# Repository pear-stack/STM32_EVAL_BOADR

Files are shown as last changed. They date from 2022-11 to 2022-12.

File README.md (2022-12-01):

# STM32_EVAL_BOARD
Simple STM32 Hardware Design
<p align="center">

</p>
<p align="center">

</p>

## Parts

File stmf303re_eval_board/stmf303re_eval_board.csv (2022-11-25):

Source: | /home/smuff/Documents/Projects/stmf303re_eval_board/stmf303re_eval_board/stmf303re_eval_board.kicad_sch
Date: | pią, 25 lis 2022, 11:23:28
Tool: | Eeschema (6.0.9)
Generator: | /usr/share/kicad/plugins/bom_csv_grouped_by_value.py
Component Count: | 31
Individual Components:
Item | Qty | Reference(s) | Value | LibPart | Footprint | Datasheet
 |  | C1 | 10u | Device:C | Capacitor_SMD:C_0603_1608Metric | ~
 |  | C2 | 100n | Device:C | Capacitor_SMD:C_0402_1005Metric | ~
 |  | C3 | 100n | Device:C | Capacitor_SMD:C_0402_1005Metric | ~
 |  | C4 | 100n | Device:C | Capacitor_SMD:C_0402_1005Metric | ~
 |  | C5 | 1u | Device:C | Capacitor_SMD:C_0603_1608Metric | ~
 |  | C6 | 100n | Device:C | Capacitor_SMD:C_0402_1005Metric | ~
 |  | C7 | 100n | Device:C | Capacitor_SMD:C_0402_1005Metric | ~
 |  | C8 | 100n | Device:C | Capacitor_SMD:C_0402_1005Metric | ~
 |  | C9 | 100n | Device:C | Capacitor_SMD:C_0402_1005Metric | ~
 |  | C10 | 30p | Device:C | Capacitor_SMD:C_0402_1005Metric | ~
 |  | C11 | 30p | Device:C | Capacitor_SMD:C_0402_1005Metric | ~
 |  | C12 | 1u | Device:C | Capacitor_SMD:C_0603_1608Metric | ~
 |  | C13 | 1u | Device:C | Capacitor_SMD:C_0603_1608Metric | ~
 |  | D1 | RED | Device:LED | LED_SMD:LED_0805_2012Metric | ~
 |  | D2 | GREEN | Device:LED | LED_SMD:LED_0805_2012Metric | ~
 |  | FB1 | 100R | Device:FerriteBead | Inductor_SMD:L_0805_2012Metric | ~
 |  | J1 | Conn_01x04_Male | Connector:Conn_01x04_Male | Connector_PinHeader_2.54mm:PinHeader_1x04_P2.54mm_Vertical | ~
 |  | J2 | USB_B_Micro | Connector:USB_B_Micro | Connector_USB:USB_Micro-B_Molex_47346-0001 | ~
 |  | J3 | Conn_01x16 | Connector_Generic:Conn_01x16 | Connector_PinSocket_2.54mm:PinSocket_1x16_P2.54mm_Vertical | ~
 |  | J4 | Conn_01x16 | Connector_Generic:Conn_01x16 | Connector_PinSocket_2.54mm:PinSocket_1x16_P2.54mm_Vertical | ~
 |  | JP1 | SolderJumper_2_Open | Jumper:SolderJumper_2_Open | Jumper:SolderJumper-2_P1.3mm_Open_RoundedPad1.0x1.5mm | ~
 |  | L1 | 27n | Device:L | Inductor_SMD:L_0402_1005Metric | ~
 |  | R1 | 10k | Device:R | Resistor_SMD:R_0603_1608Metric | ~
 |  | R2 | 10k | Device:R | Resistor_SMD:R_0603_1608Metric | ~
 |  | R3 | 1k5 | Device:R | Resistor_SMD:R_0603_1608Metric | ~
 |  | R4 | 1k5 | Device:R | Resistor_SMD:R_0603_1608Metric | ~
 |  | R5 | 1k5 | Device:R | Resistor_SMD:R_0603_1608Metric | ~
 |  | SW1 | SW_DPST_x2 | Switch:SW_DPST_x2 | Button_Switch_SMD:SW_SPST_CK_RS282G05A3 | ~
 |  | U1 | STM32F303RETx | MCU_ST_STM32F3:STM32F303RETx | Package_QFP:LQFP-64_10x10mm_P0.5mm | http://www.st.com/st-web-ui/static/active/en/resource/technical/document/datasheet/DM00118585.pdf
 |  | U2 | XC6206PxxxMR | Regulator_Linear:XC6206PxxxMR | Package_TO_SOT_SMD:SOT-23 | https://www.torexsemi.com/file/xc6206/XC6206.pdf
 |  | Y1 | 8MHz | Device:Crystal | Crystal:Crystal_SMD_0603-2Pin_6.0x3.5mm | ~
Collated Components:
Item | Qty | Reference(s) | Value | LibPart | Footprint | Datasheet
1 | 1 | C1 | 10u | Device:C | Capacitor_SMD:C_0603_1608Metric | ~
2 | 7 | C2, C3, C4, C6, C7, C8, C9 | 100n | Device:C | Capacitor_SMD:C_0402_1005Metric | ~
3 | 3 | C5, C12, C13 | 1u | Device:C | Capacitor_SMD:C_0603_1608Metric | ~
4 | 2 | C10, C11 | 30p | Device:C | Capacitor_SMD:C_0402_1005Metric | ~
5 | 1 | D1 | RED | Device:LED | LED_SMD:LED_0805_2012Metric | ~
6 | 1 | D2 | GREEN | Device:LED | LED_SMD:LED_0805_2012Metric | ~
7 | 1 | FB1 | 100R | Device:FerriteBead | Inductor_SMD:L_0805_2012Metric | ~
8 | 1 | J1 | Conn_01x04_Male | Connector:Conn_01x04_Male | Connector_PinHeader_2.54mm:PinHeader_1x04_P2.54mm_Vertical | ~
9 | 1 | J2 | USB_B_Micro | Connector:USB_B_Micro | Connector_USB:USB_Micro-B_Molex_47346-0001 | ~
10 | 2 | J3, J4 | Conn_01x16 | Connector_Generic:Conn_01x16 | Connector_PinSocket_2.54mm:PinSocket_1x16_P2.54mm_Vertical | ~
11 | 1 | JP1 | SolderJumper_2_Open | Jumper:SolderJumper_2_Open | Jumper:SolderJumper-2_P1.3mm_Open_RoundedPad1.0x1.5mm | ~
12 | 1 | L1 | 27n | Device:L | Inductor_SMD:L_0402_1005Metric | ~
13 | 2 | R1, R2 | 10k | Device:R | Resistor_SMD:R_0603_1608Metric | ~
14 | 3 | R3, R4, R5 | 1k5 | Device:R | Resistor_SMD:R_0603_1608Metric | ~
15 | 1 | SW1 | SW_DPST_x2 | Switch:SW_DPST_x2 | Button_Switch_SMD:SW_SPST_CK_RS282G05A3 | ~
16 | 1 | U1 | STM32F303RETx | MCU_ST_STM32F3:STM32F303RETx | Package_QFP:LQFP-64_10x10mm_P0.5mm | http://www.st.com/st-web-ui/static/active/en/resource/technical/document/datasheet/DM00118585.pdf
17 | 1 | U2 | XC6206PxxxMR | Regulator_Linear:XC6206PxxxMR | Package_TO_SOT_SMD:SOT-23 | https://www.torexsemi.com/file/xc6206/XC6206.pdf
18 | 1 | Y1 | 8MHz | Device:Crystal | Crystal:Crystal_SMD_0603-2Pin_6.0x3.5mm | ~

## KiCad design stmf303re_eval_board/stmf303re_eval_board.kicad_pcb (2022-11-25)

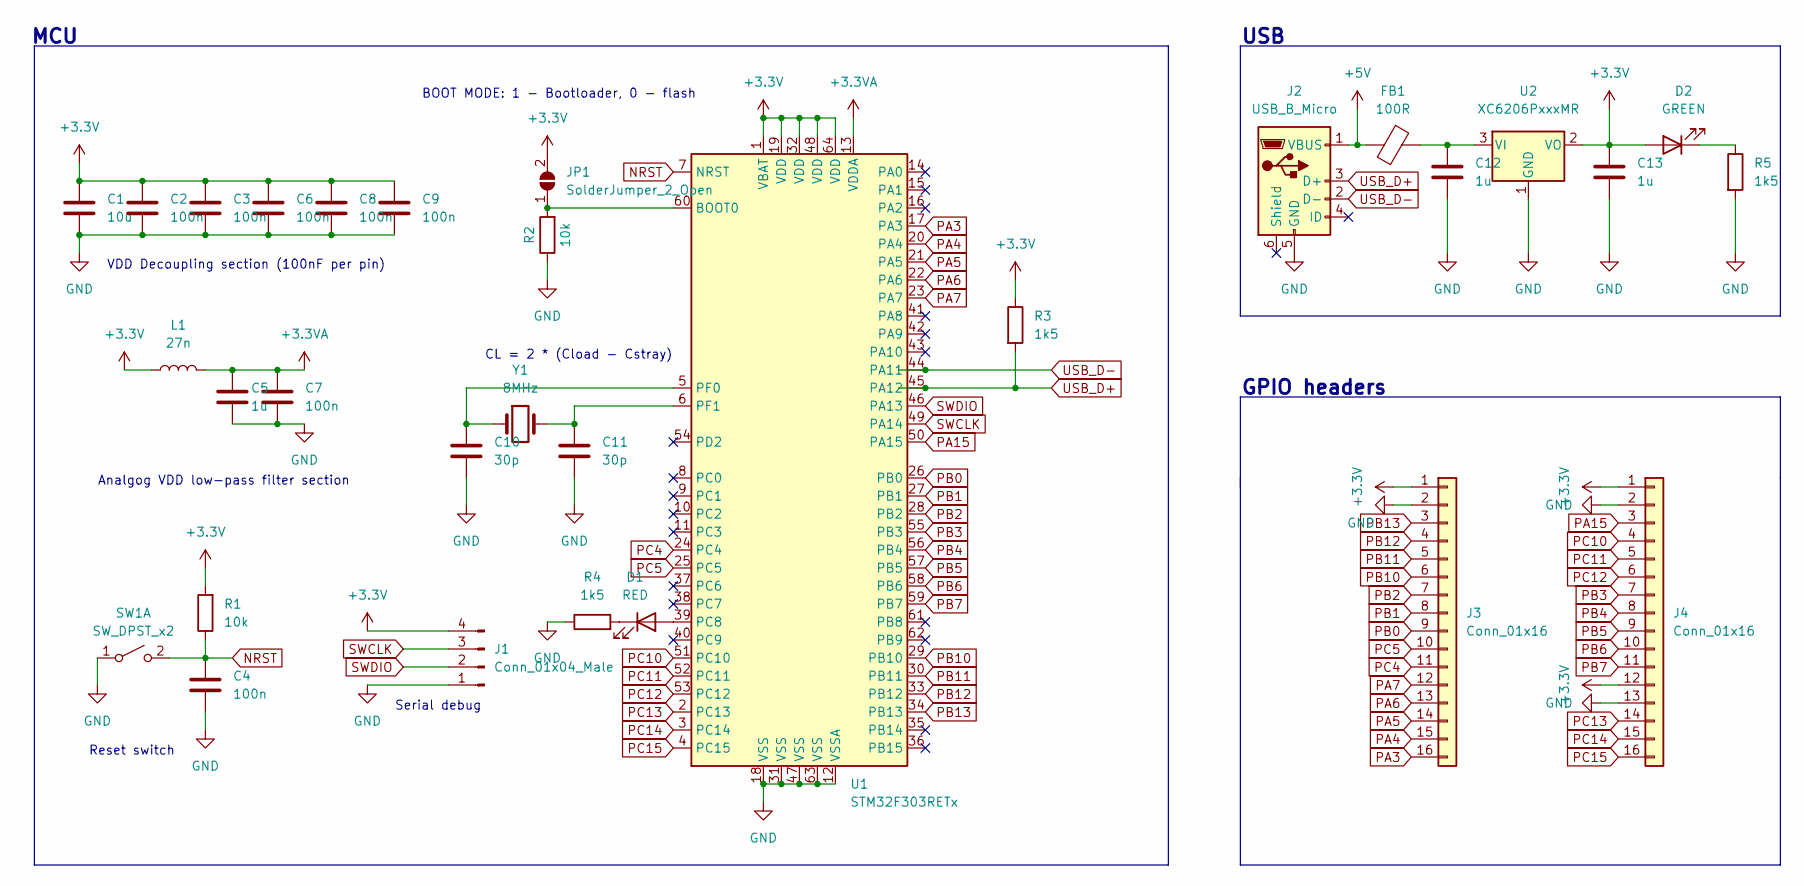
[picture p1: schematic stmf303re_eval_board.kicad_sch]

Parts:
C1: 10u; C_0603_1608Metric
C2, C3, C4, C6, C7, C8, C9: 100n; C_0402_1005Metric
C5, C12, C13: 1u; C_0603_1608Metric
C10, C11: 30p; C_0402_1005Metric
D1: RED; LED_0805_2012Metric
D2: GREEN; LED_0805_2012Metric
FB1: 100R; L_0805_2012Metric
J1: Conn_01x04_Male; PinHeader_1x04_P2.54mm_Vertical
J2: USB_B_Micro; USB_Micro-B_Molex_47346-0001
J3, J4: Conn_01x16; PinSocket_1x16_P2.54mm_Vertical
JP1: SolderJumper_2_Open; SolderJumper-2_P1.3mm_Open_RoundedPad1.0x1.5mm
L1: 27n; L_0402_1005Metric
R1, R2: 10k; R_0603_1608Metric
R3, R4, R5: 1k5; R_0603_1608Metric
SW1: SW_DPST_x2; SW_SPST_CK_RS282G05A3
U1: STM32F303RETx; LQFP-64_10x10mm_P0.5mm
U2: XC6206PxxxMR; SOT-23
Y1: 8MHz; Crystal_SMD_0603-2Pin_6.0x3.5mm

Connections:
+3.3V: C1.1, C2.1, C3.1, C6.1, C8.1, C9.1, C13.1, D2.2 (A), J1.4, J3.1, J4.1, J4.12, JP1.2 (B), L1.1, R1.2, R3.1, U1.1 (VBAT), U1.19 (VDD), U1.32 (VDD), U1.48 (VDD), U1.64 (VDD), U2.2 (VO)
+3.3VA: C5.1, C7.1, L1.2, U1.13 (VDDA)
+5V: FB1.1, J2.1 (VBUS)
GND: C1.2, C2.2, C3.2, C4.2, C5.2, C6.2, C7.2, C8.2, C9.2, C10.2, C11.2, C12.2, C13.2, J1.1, J2.5 (GND), J3.2, J4.2, J4.13, R2.1, R4.1, R5.2, SW1.1 (A), U1.12 (VSSA), U1.18 (VSS), U1.31 (VSS), U1.47 (VSS), U1.63 (VSS), U2.1 (GND)
NRST: C4.1, R1.1, SW1.2 (B), U1.7 (NRST)
unnamed: C10.1, U1.5 (PF0), Y1.1
unnamed: C11.1, U1.6 (PF1), Y1.2
unnamed: C12.1, FB1.2, U2.3 (VI)
unnamed: D1.1 (K), R4.2
unnamed: D1.2 (A), U1.39 (PC8)
unnamed: D2.1 (K), R5.1
unnamed: JP1.1 (A), R2.2, U1.60 (BOOT0)
PA3: J3.16, U1.17 (PA3)
PA4: J3.15, U1.20 (PA4)
PA5: J3.14, U1.21 (PA5)
PA6: J3.13, U1.22 (PA6)
PA7: J3.12, U1.23 (PA7)
PA15: J4.3, U1.50 (PA15)
PB0: J3.9, U1.26 (PB0)
PB1: J3.8, U1.27 (PB1)
PB2: J3.7, U1.28 (PB2)
PB3: J4.7, U1.55 (PB3)
PB4: J4.8, U1.56 (PB4)
PB5: J4.9, U1.57 (PB5)
PB6: J4.10, U1.58 (PB6)
PB7: J4.11, U1.59 (PB7)
PB10: J3.6, U1.29 (PB10)
PB11: J3.5, U1.30 (PB11)
PB12: J3.4, U1.33 (PB12)
PB13: J3.3, U1.34 (PB13)
PC4: J3.11, U1.24 (PC4)
PC5: J3.10, U1.25 (PC5)
PC10: J4.4, U1.51 (PC10)
PC11: J4.5, U1.52 (PC11)
PC12: J4.6, U1.53 (PC12)
PC13: J4.14, U1.2 (PC13)
PC14: J4.15, U1.3 (PC14)
PC15: J4.16, U1.4 (PC15)
SWCLK: J1.3, U1.49 (PA14)
SWDIO: J1.2, U1.46 (PA13)
USB_D+: J2.3 (D+), R3.2, U1.45 (PA12)
USB_D-: J2.2 (D-), U1.44 (PA11)

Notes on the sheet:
USB
Reset switch
Serial debug
GPIO headers
CL = 2 * (Cload - Cstray)
BOOT MODE: 1 - Bootloader, 0 - flash
Analgog VDD low-pass filter section
MCU
VDD Decoupling section (100nF per pin)

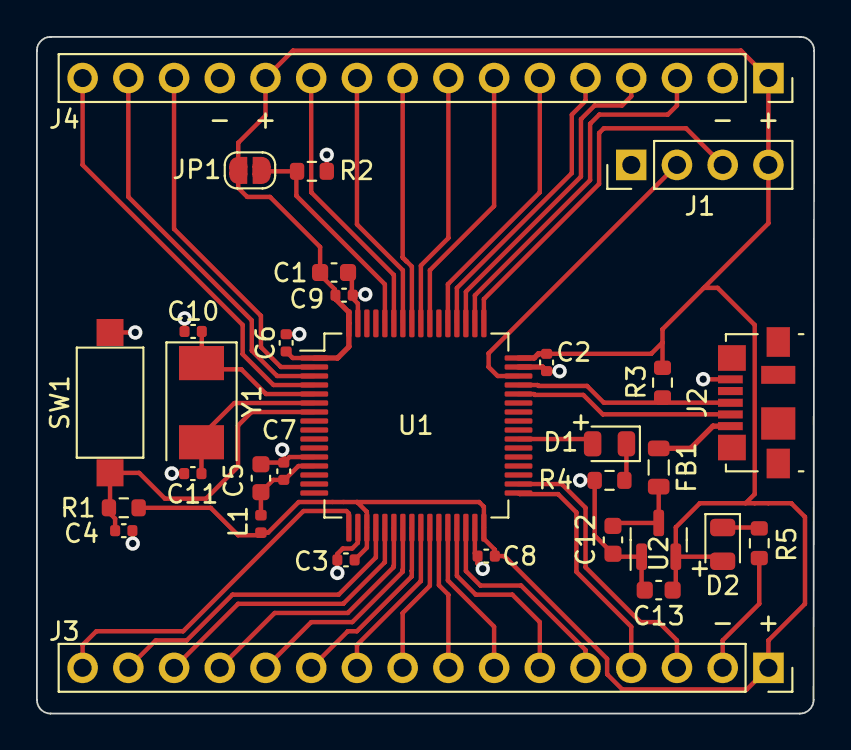
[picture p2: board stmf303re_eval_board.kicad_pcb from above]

Board: 2 copper layers, 43.2 x 37.6 mm, 31 parts (0 on the bottom side), 42 nets.

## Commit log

2022-10-21 init commit
    [stmf303re_eval_board.kicad_pcb, stmf303re_eval_board.kicad_sch]
2022-10-21 basic scheme, footprint and layout
    [stmf303re_eval_board.kicad_pcb, stmf303re_eval_board.kicad_sch]
2022-11-24 usb, traces fixed
    [stmf303re_eval_board.kicad_pcb, stmf303re_eval_board.kicad_sch]
2022-11-25 traces update
    [stmf303re_eval_board-B_Cu.gbr, stmf303re_eval_board-B_Mask.gbr, stmf303re_eval_board-B_Paste.gbr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]
